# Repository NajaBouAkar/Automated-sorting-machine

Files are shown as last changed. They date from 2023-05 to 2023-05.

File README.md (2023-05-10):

# Automated-sorting-machine

# Installation
Use the package manager pip to install
```bash
pip install python-socketio
```
```bash
pip install scikit-fuzzy
```
```bash
pip install math smbus time
```
```bash 
pip install numpy
```
```bash
apt-get install rpi.gpio
```
You also have to download a git repo to be able to use the MPUs
```bash
git clone https://github.com/rocheparadox/Kalman-Filter-Python-for-mpu6050.git
```
Now for the installation on the laptop
```bash
pip install scikit-fuzzy
```
```bash
pip install numpy
```
```bash
pip install opencv-python
```

# Implementation
To run the code you fisrt have to get the IP address from the pi and replace it in the code running on the laptop. After that you run the code on the pi then you run the code on the laptop and the sorting will start.
Note: you need to place the dnn model in the same directory as your code.

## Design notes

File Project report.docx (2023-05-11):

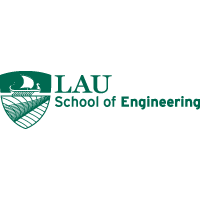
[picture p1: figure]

# LEBANESE AMERCIAN UNIVERSITY

# MCE411– Mechatronic System Design 2

# Doctor Noel Maalouf

# Project report

# Rami Hjeij: #ID 202001988

# Hassan Al Hakim #ID 202000443

# Naja Bou Akar #ID 202000174

Date of Submission: 5/10/2023

# Figures:

# Methodology:

## Design:

To layout the three degree of freedom robot arm with a gripper that is capable of picking up and sorting cups and bottles which are located on a conveyor belt, we accompanied a based technique that concerned numerous key steps. First, we performed a thorough evaluation of the problem and the favored outcome, along with an in depth examine of the conveyor belt, the objects to be picked up, and the overall surroundings. We then evolved a clean and concise specification for the robotic arm, such as its size, weight, and variety of movement, as well as the desired accuracy and precision for object detection and sorting.

Next, we used an existing layout for the robot arm that we got from grabCAD, which include motors, sensors, contemplating factors such as price, reliability, and simplicity of integration.

Once the design was finalized, we proceeded to construct and take a look at the robot arm, iteratively refining and enhancing its capability primarily based on the consequences of our assessments. Finally, we included the arm with the object detection machine and conveyor belt manipulate mechanism, ensuring seamless communique and coordination among all additives. This technique allowed us to design and construct an excellent robot arm that meets the specific necessities of the application efficiently and correctly.

### Robotic arm:

- 3D printed robotic arm
- 3 MG996R servos
- 1 SG90 9g servo
- 2 MPU 6050
- Screws
- 2 Lithium batteries (3.7V)

As shown in the figure, the robotic arm comprises a rotating base link and two moving links, in addition to a gripper that has the ability to open and close. The two MPUs located on the moving links provide the actual angle of each link, which can serve as input for the fuzzy logic controller responsible for the arm's movements.

To power the servo motors, two lithium batteries are utilized, which supply the rated voltage required. Additionally, the servo motors share common ground with the Raspberry Pi.

However, due to a malfunction in one of the MPUs, the arm was ultimately designed to operate with only three degrees of freedom instead of the originally intended four degrees.

### Conveyor belt:

- 12 V DC motor (high torque)
- Metal coupling
- 5 bearings
- 2 pipes
- Rubber
- Screws and bolts
- H-bridge
- AC to DC transformer (220VAC to 12VDC)
- Grease

As shown in the figure above, the conveyor belt is equipped with five bearings, four of which are inserted inside the green pipes. These pipes have a metallic rod inserted through them, which functions as a center axis. Three of these metallic rods will be fixed to the chassis of the belt, while the fourth one will be fixed to the coupling. The coupling, in turn, will be attached to the motor, such that when the motor rotates, the entire belt will rotate.

To power the motor, a transformer is used to supply rated voltage for the h-bridge which also shares common ground with the Raspberry Pi.

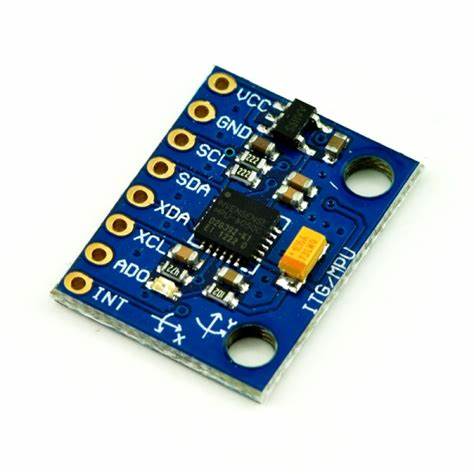
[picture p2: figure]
Triple Axis Accelerometer & Gyro - MPU-6050

Figure 1:MPU6050

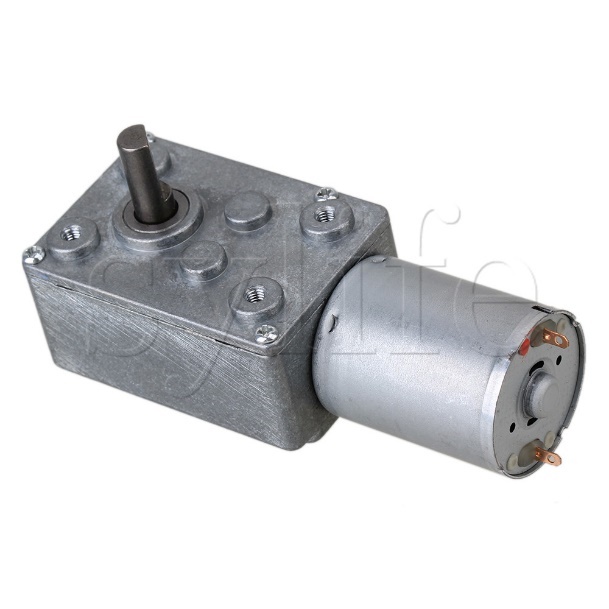
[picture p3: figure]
High Torque 12V DC 120rpm DC Worm Geared Motor With Gear Reducer Turbo ...

Figure 2: High Torque 12V DC Motor

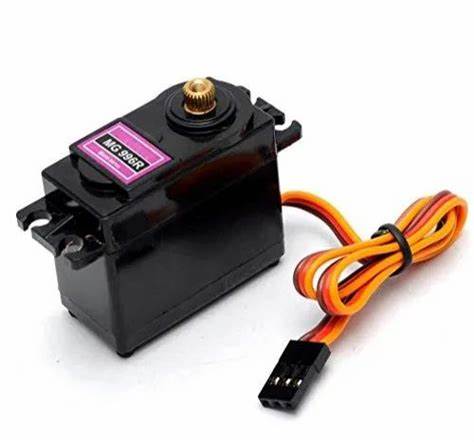
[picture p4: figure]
Mg996 Towerpro Mg996r High Torque Metal Gear Servo Motor 360 Degree ...

Figure 3: MG996R Servo Motor

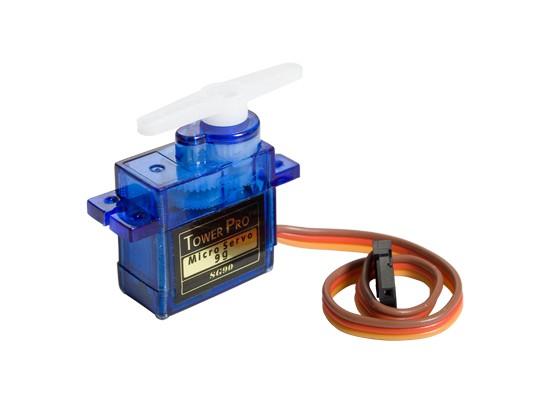
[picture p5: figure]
Makerobot Education: Servo Motor Interfacing With Arduino Uno

Figure 4: SG90 9g Servo Motor

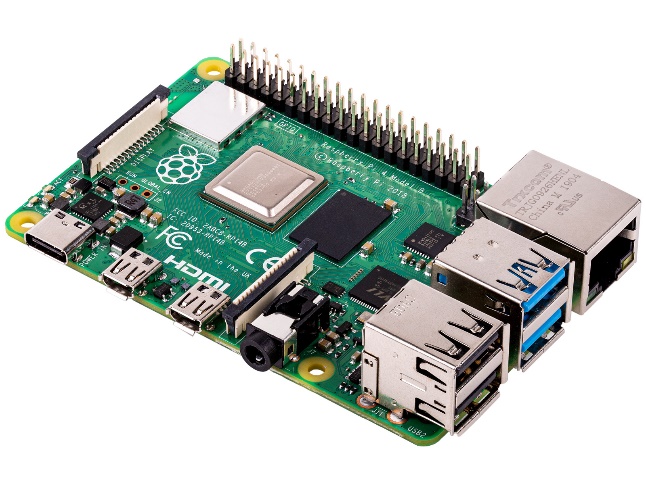
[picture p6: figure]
Raspberry Pi 4 released - everything changes, but the price remains the ...

Figure 5: Raspberry Pi 4

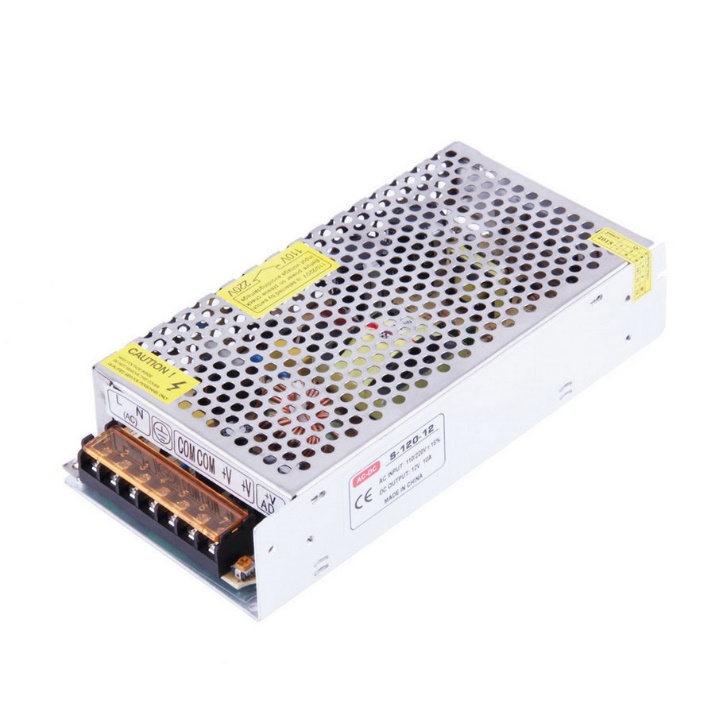
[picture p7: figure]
AC 120V 220V To DC 12V Regulated Transformer Power Supply For LED Strip ...

Figure 6: AC to DC transformer (220VAC to 12VDC)

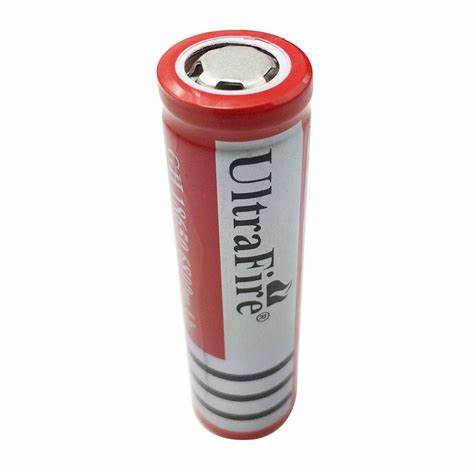
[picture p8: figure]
1/2/4/6/10pcs Flat Top 18650 Batterie 6800mAh 3.7V Li-ion Rechargeable ...

Figure 7: 3.7V 6800mah lithium battery

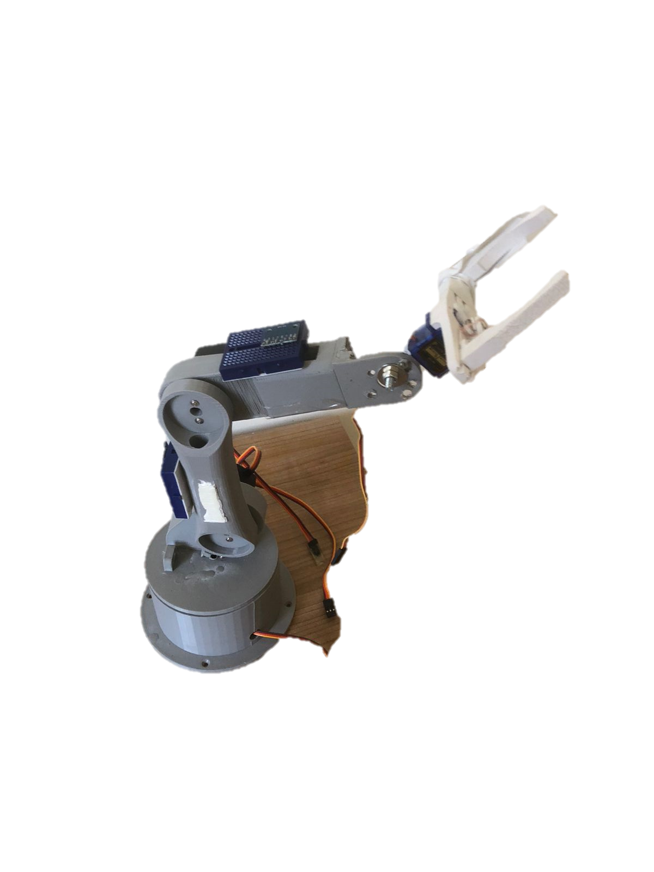
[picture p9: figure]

Figure 8: 3D printed Robotic Arm

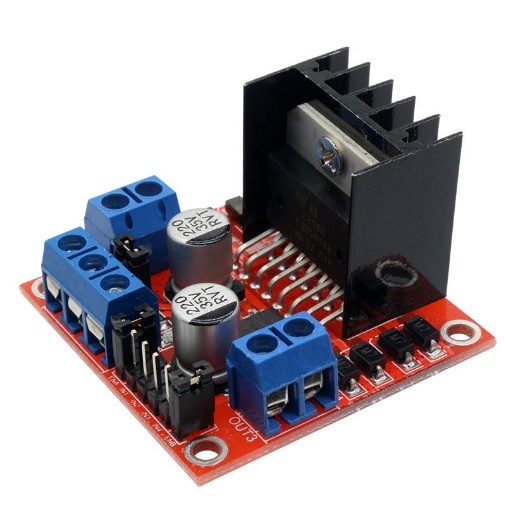
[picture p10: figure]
L298N H-Bridge Stepper Motor Driver Module for Arduino | Satistronix Group

Figure 9: L298 H-Bridge

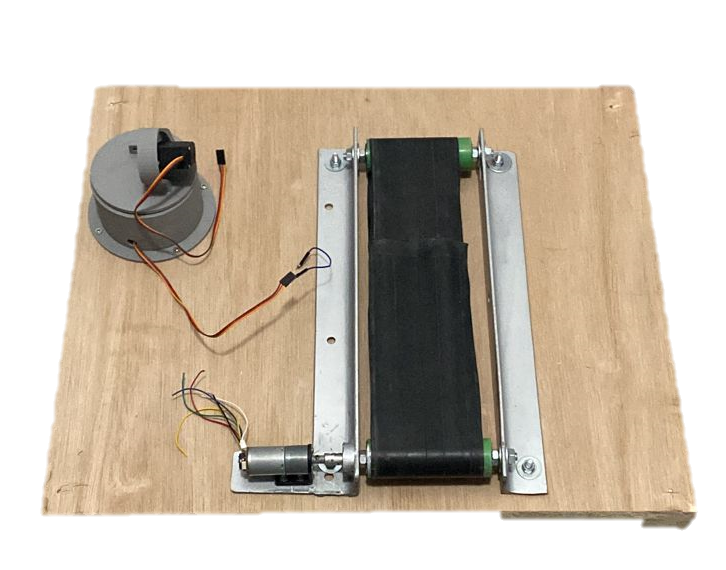
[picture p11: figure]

Figure 10: Conveyer Belt with its base

## Simulation:

We utilized two Fuzzy Logic controllers to control our system. The first controller was used for the belt, and it relied on the centered pixel of the object as feedback. The second controller was used for the robotic arm, and it relied on feedback from the MPU6050 sensor from two different links.

### Belt:

To obtain the universe of discourse, we measured the position of the pixel along the x-axis at different locations on the belt, as well as the desired pixel position. The output of the fuzzy logic is a Pulse Width Modulation (PWM) signal, which is then sent to the motor. Furthermore, we tested the angular velocity for different PWM outputs to determine the desired universe of discourse for the output. All of the codes were implemented using Python and the SKFuzzy library.

Figure 11: Universe of discourse of the bottle

Figure 12: Universe of discourse of the Cup.

To take enough data about the x-coordinates that will be faced in our application, we turned on the motor with the bottle on the belt so that the model can detect the bottle on different positions until reaching the desired position. Then we printed the x-coordinates for all the positions that were detected by the model as shown above. The same was done to know the universe of discourse for the cup. From the data shown in the figure above we chose that the universe of discourse must be between 900 and 580 (which is the desired position). Also, from the increments we got we chose the membership functions for the input as shown in fig.13:

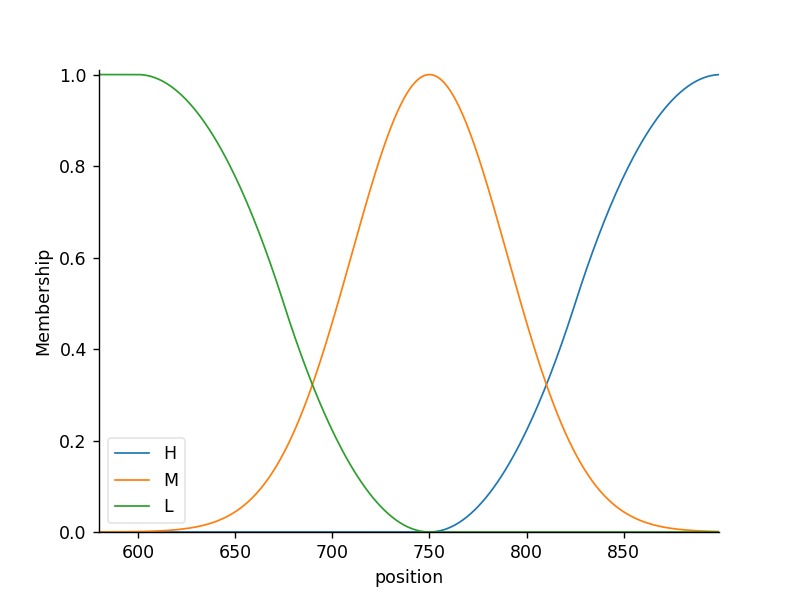
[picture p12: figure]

Figure 13: Input membership function of the belt

Figure 14: Python code for input membership functions

The universe of discourse is [580,900].

Our desired pixel is 580.

Low is from 580 to 750.

Medium is 600 to 900.

High is from 750 to 900.

All parameters have been chosen experimentally.

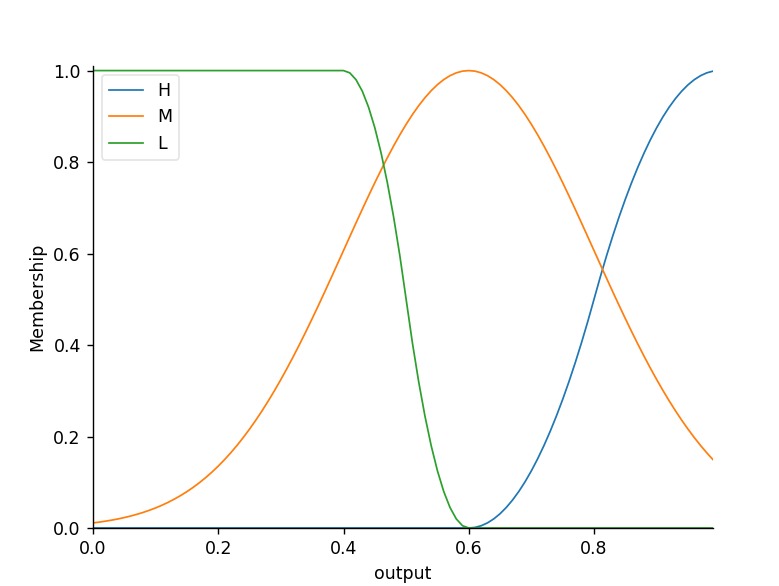
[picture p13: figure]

Figure 15: Python code for the output

Universe of discourse is [0 1].

Low is from 0 to 0.6.

Medium is 0 to 1.

High is from 0.6 to 1.

Also, parameters have been chosen experimentally. The experiments were testing the speed of the belt when subjected to multiple PWM signals.

Figure 16:Python code for the rules of the belt controller

The rules were as follow:

If the position is high then the output is high.

If the position is medium then the output is medium.

If the position is low then the output is low.

Figure 17: Output to a given input

For an input of 650 which means that our center of our object x-axis coordinate is equal to 650 the output to be given to the motor is 0.28.

### Robotic arm:

The assumed input universe of discourse ranges from -90 to 90 degrees, since the servo motor rotates from 0 to 180 degrees. As a result, if the error were to be greater than 90 or less than -90 degrees, it would indicate a malfunction in the servo motor. The output universe of discourse is set between -10 to 10 to ensure that the process runs smoothly, without any sudden or aggressive changes.

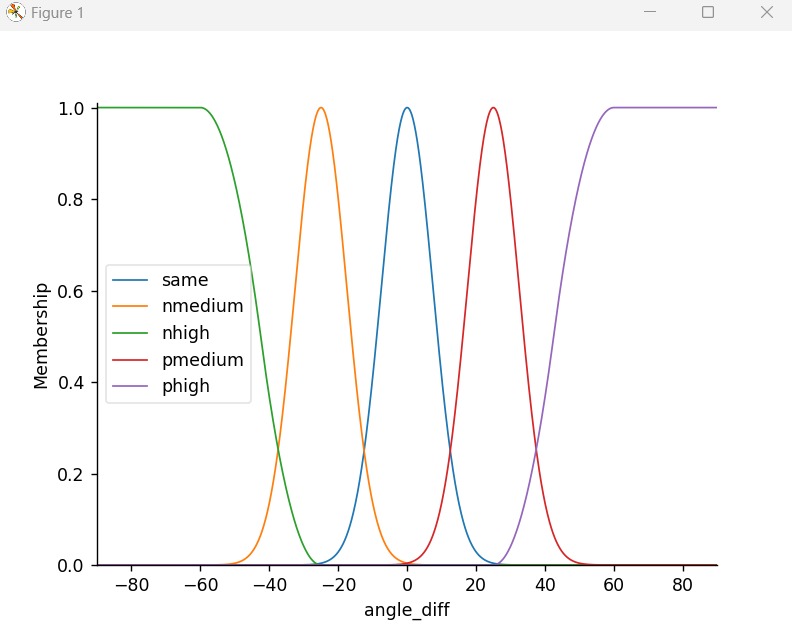
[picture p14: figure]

Figure 18: Input membership function

Figure 19: Python code to create input membership function

The input provided is the difference between the desired angle and the current angle of the links. The angle difference can fall within different ranges. It can be the same, ranging from -25 to 25. It can also be negative and medium, ranging from -50 to 0. Alternatively, it can be negative and high, ranging from -90 to -25. Additionally, it can be positive and medium, ranging from 0 to 50, and finally, positive, and high, ranging from 25 to 90.

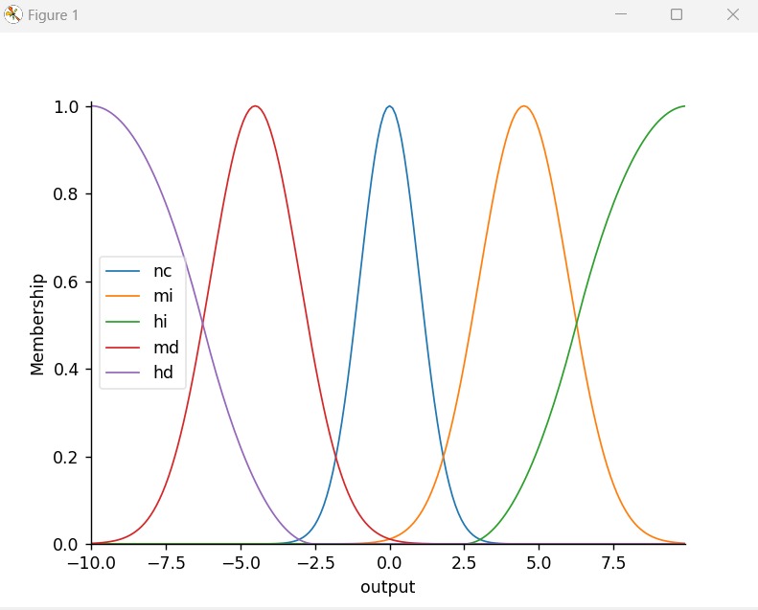
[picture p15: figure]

Figure 20: Output Membership functions

The resulting output is the angle that needs to be added to the current servo motor angle. This angle can also indicate no change, ranging between -3 to 3 degrees. It can also indicate a medium increase, ranging from 0 to 8 degrees, and a high increase, ranging from 2.5 to 10 degrees. Additionally, it can indicate a medium decrease, ranging from -10 to 0 degrees, and finally, a high decrease, ranging from -10 to -2.5 degrees.

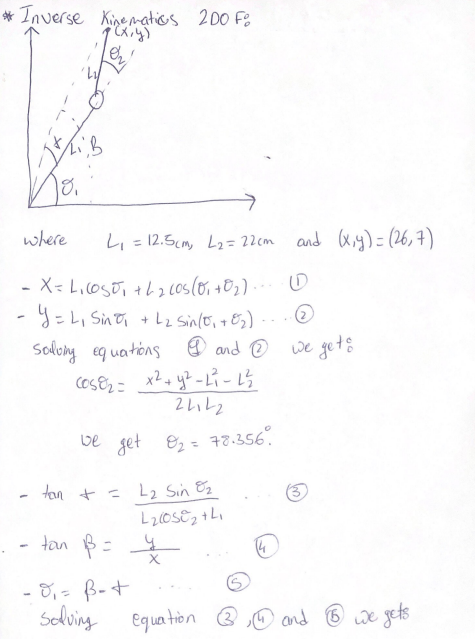
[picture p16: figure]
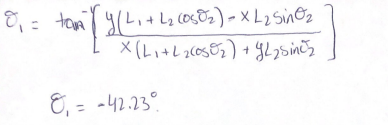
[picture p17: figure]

Figure 21: Inverse Kinematic

To determine the desired angle output for each link, we used inverse kinematics after measuring the x and y coordinates of our object with respect to the center of our robotic arm:

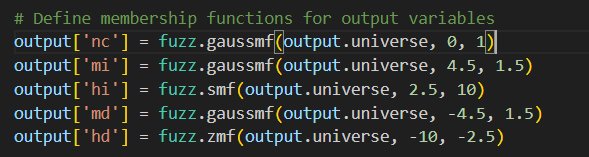
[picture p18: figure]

Figure 22: Python code to create output membership functions

Figure 23: Sample input testing

An example output was obtained when the input value was set to 10, resulting in an output of 1.755.

## Implementation:

### Process of sorting:

Our object detection code relied on a pretrained YOLOv4 model running on a laptop with an external webcam. To communicate with the Raspberry Pi, we established a socket connection, where the laptop acted as the server, transmitting information to the client (Raspberry Pi). The client was designed to wait for a connection before executing the code. Mainly the code on the laptop will take the video from the webcam, use the computer vision model to detect at each frame if there is bottle or cup. Moreover, the x-coordinate position of the object will be fed to the fuzzy logic controller, and the controller will provide the needed PWM signal for the motor. Then this output will be transmitted as a string to the raspberry pi code through a socket, the code on the pi will decode it and feed it to the motor.

Once the object detection and fuzzy logic control of the belt processing were complete, the laptop would send a required PWM signal to the motor. The fuzzy logic controller would then execute again on the laptop to obtain another PWM signal, appropriate for the new position of the object. This process would repeat until convergence was reached, at which point the roles would reverse, with the Raspberry Pi becoming the server and the laptop becoming the client.

After the belt fuzzy controller converged, we used a fuzzy logic controller to set the robotic arm in the desired position, grab the object, and transport it to its corresponding location on the left or right of the arm. Once the object was sorted, the Raspberry Pi would send a signal to the laptop via sockets indicating that the process was complete, triggering the object detection code and fuzzy logic controller of the belt on the laptop to repeat the process.

## Problems in the testing phase:

1- Model Training: First, we decided to train our own model that supports and differentiates between two different well-defined objects. So, we started with a dataset of 300 images and we used roboflow to annotate our images and got our XML files. Now for the training we trained using the mobilenet SSD V2 (which has very fast inferencing time and high accuracy). After the training had finished, we converted our model to a tflite model and deployed it on the raspberry pi. When it was deployed the model was acting weird and was detecting everything and labeling them as a bottle. Second, we thought that we needed a bigger dataset so we took 500 more pictures to have a total of 800 images to train our model. In addition to the new pictures, we augmented the data to finally have a total of 2100 images to train our model. However, we still had the same error. That is why we decided to use a pretrained YOLOV4 model that we downloaded online. This model can differentiate between 73 classes but we only used two classes (bottle and cup).
2- MPU calibration: When the MPUs were tested they were giving inaccurate data so we needed to apply the Kalman Filter algorithm which stabilized the outputs of the MPUs. The code for the Kalman filter algorithm was downloaded from a GitHub repository named Kalman.
3- 3 DOF: The initial design of the robot was a four degree of freedom mechanism, however one of the three MPUs was defective, so we fixed one of the Links.
4- Resistors: In order to have one power supply for the machine, we tried to use 4.7-ohm resistors to divide the voltage from 12V to 5V to feed the servo motors. However, the resistors did not withstand the current absorbed by the servos. To solve this problem, we were obligated to use two 3.7V lithium batteries to supply the servo motors alone.
5- Servo Motors: The MG996R servo motors have a problem in holding their position which creates some oscillations in their behavior. Also, when testing the gripper its servo motor malfunctioned suddenly, so we used another gripper that was available that uses the SG90 servo motor.

# Results and Limitations:

## Limitations:

1- The robotic arm can be implemented with more stable servo motors which can increase the accuracy of the machine.
2- Our model operates properly in certain lighting conditions, a better model can be implemented which will make the machine more reliable.
3- Our machine is trained to sort only two objects, which are the bottle and the cup.
4- Camera calibration techniques can be used so that the model can operate properly regardless of its position.

## Results:

We are pleased to present the results of our project which exceeded all expectations and proved to be a great success. Our team’s unwavering commitment that helped us overcome all the challenges that we encountered through our journey in this project, meticulous planning and relentless pursuit of excellence have allowed us to achieve incredible results. By employing innovative techniques and using cutting-edge technology we were able to make the automated sorting machine that was able to continuously sort a bottle and a cup using computer vision. All fuzzy controllers were working with high efficiency and accuracy and the connection between the laptop and the raspberry pi was very effective and working very smoothly.

Project git hub repository:

https://github.com/RamiHjeij/Autonomous-Sorting-Machine.git

Video: https://drive.google.com/file/d/1pVdlkhVqWchsBrMoY4FO01Fo6XS_HtjN/view?usp=sharing

# References:

https://github.com/rocheparadox/Kalman-Filter-Python-for-mpu6050.git

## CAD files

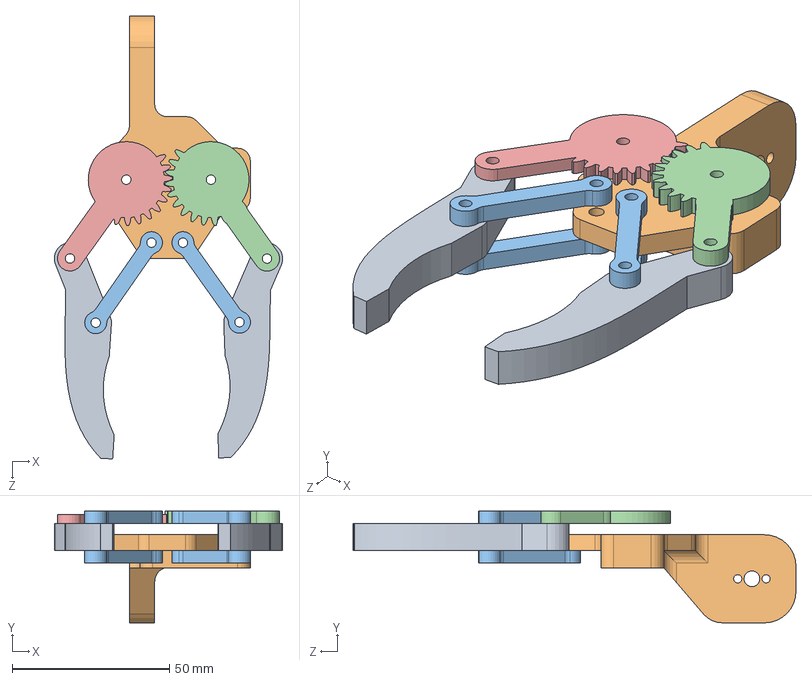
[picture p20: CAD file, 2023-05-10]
SW file/Gripper/Gripper Assembly_r1.SLDASM
72.5 x 35.5 x 140.7 mm
gear1_r1
gear2_r1
grip link 1_r1 x 4
Gripper base_r1
Gripper 1_r1 x 2

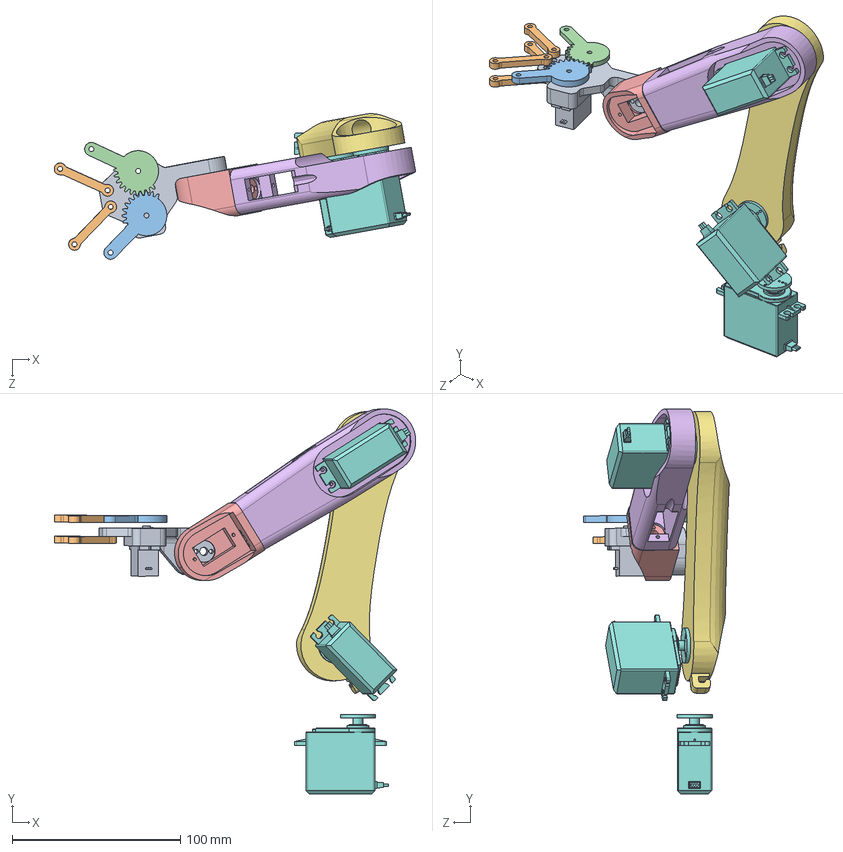
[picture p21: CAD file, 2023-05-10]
SW file/Robotic Arm.SLDASM
214.9 x 228.9 x 86.7 mm
Servo Motor MG996R x 3
Arm 01
Arm 02 v3
Arm 03
gear1
gear2
grip link 1 x 4
Gripper base
Servo Motor Micro 9g

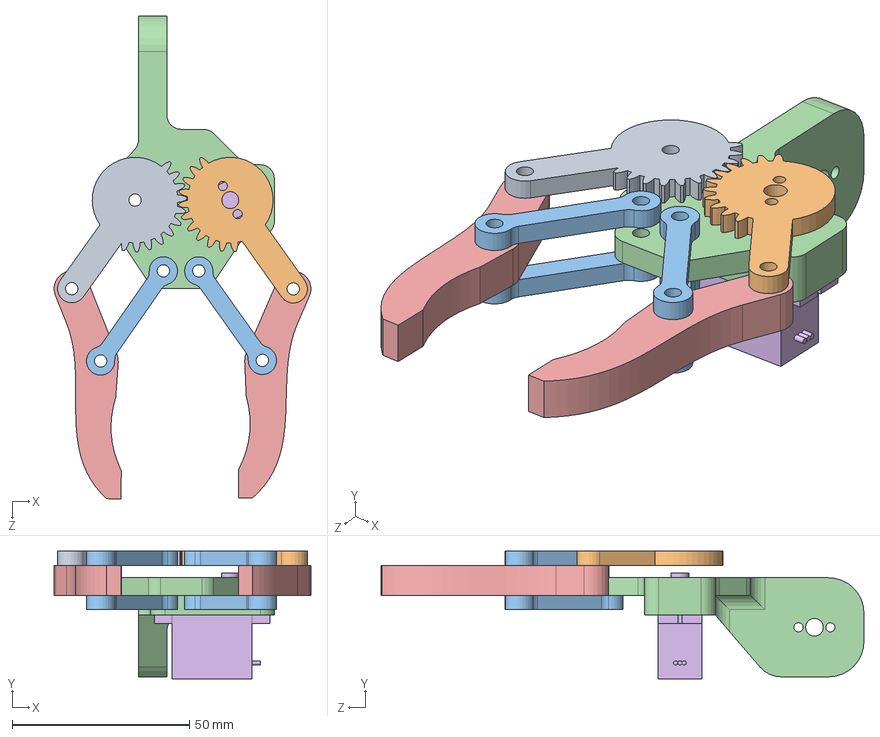
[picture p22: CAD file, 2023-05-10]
SW file/Gripper/Gripper Assembly.SLDASM
72.5 x 36.0 x 136.4 mm
gear1
gear2
grip link 1 x 4
Gripper base
Gripper 1 x 2
Servo Motor Micro 9g

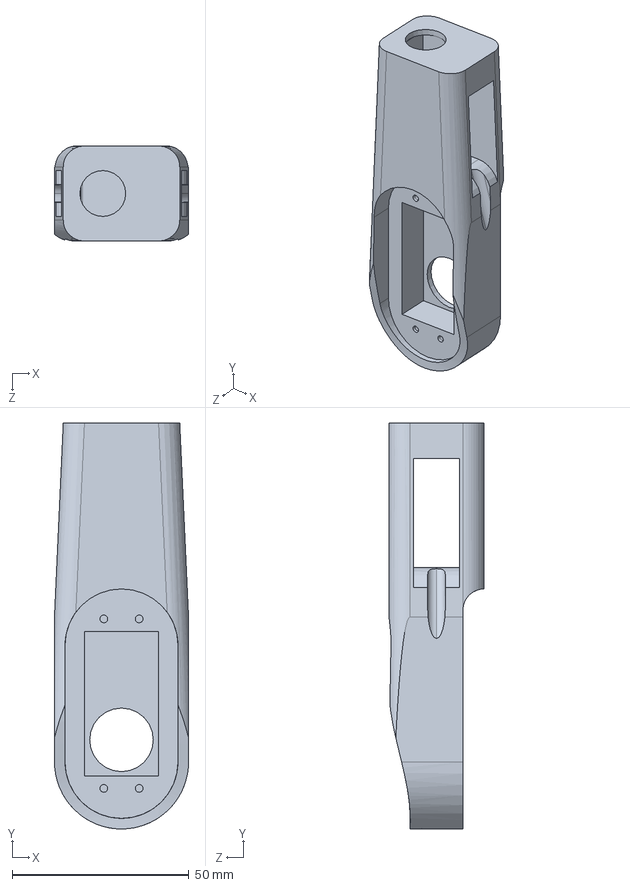
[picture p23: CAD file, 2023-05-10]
SW file/Arm 02 v3_r1.SLDPRT
38.0 x 115.0 x 27.0 mm

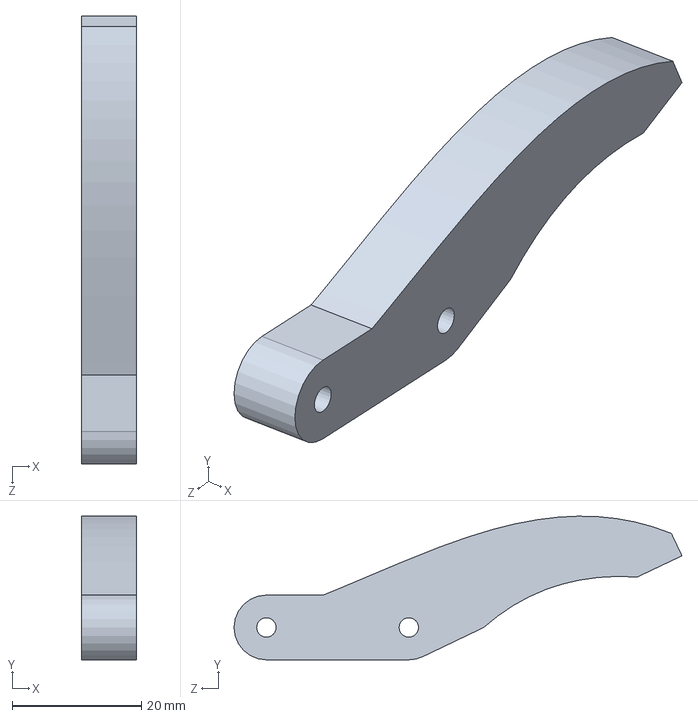
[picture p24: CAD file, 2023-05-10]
SW file/Gripper/Gripper 1_r1.SLDPRT
8.50 x 22.2 x 69.2 mm

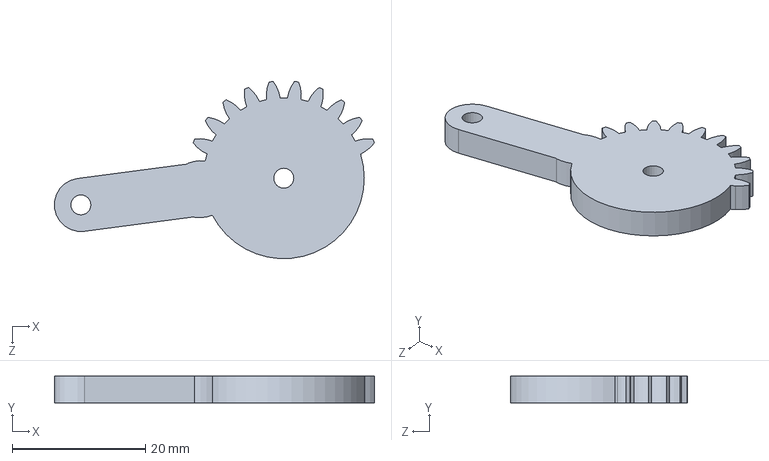
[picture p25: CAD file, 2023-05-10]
SW file/Gripper/gear2_r1.SLDPRT
48.1 x 4.00 x 26.6 mm

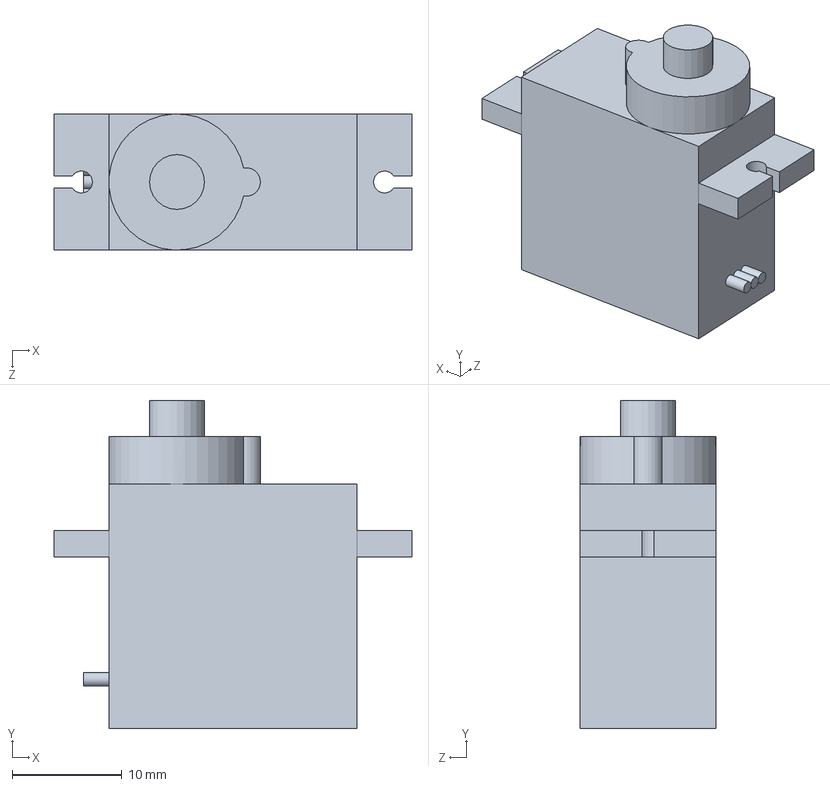
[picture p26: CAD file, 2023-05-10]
SW file/Servo Motor Micro 9g.SLDPRT
32.6 x 29.9 x 12.4 mm

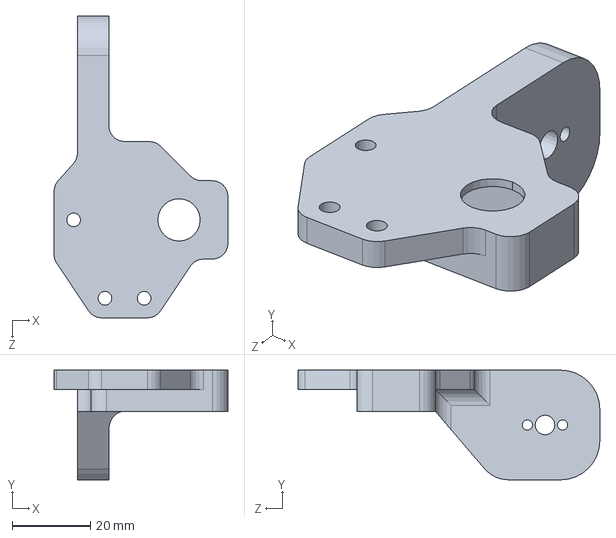
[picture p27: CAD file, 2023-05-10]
SW file/Gripper/Gripper base_r1.SLDPRT
44.4 x 28.0 x 77.0 mm

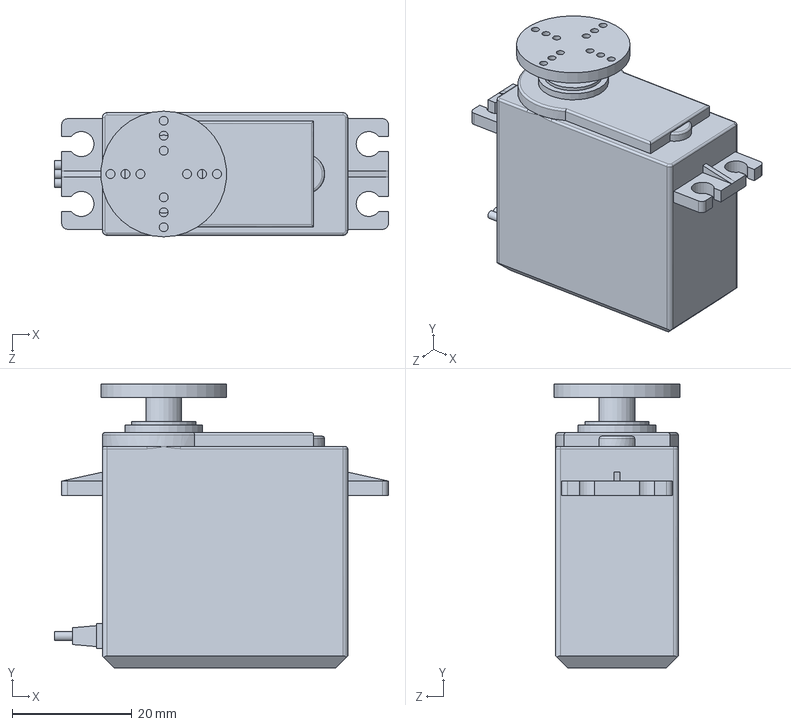
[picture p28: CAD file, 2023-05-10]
SW file/Servo Motor MG996R.SLDPRT
55.8 x 47.4 x 21.0 mm

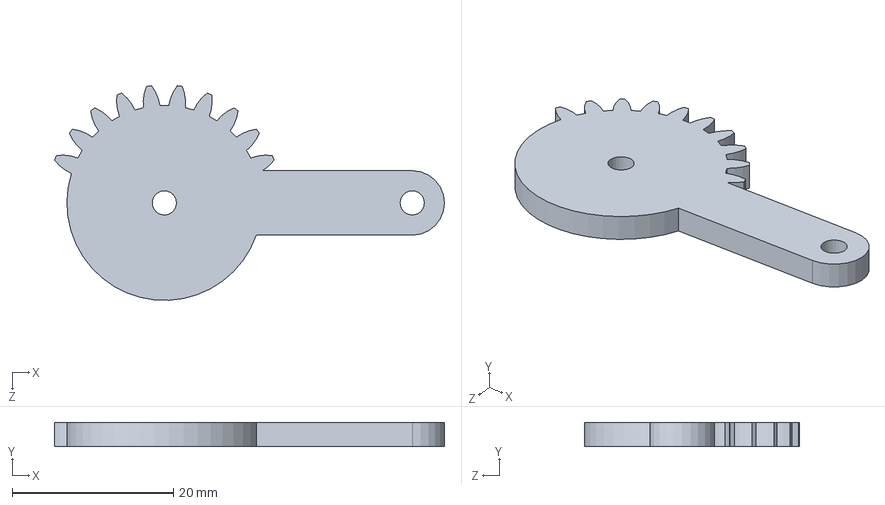
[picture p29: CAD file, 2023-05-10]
SW file/Gripper/gear1.SLDPRT
48.4 x 3.00 x 26.6 mm

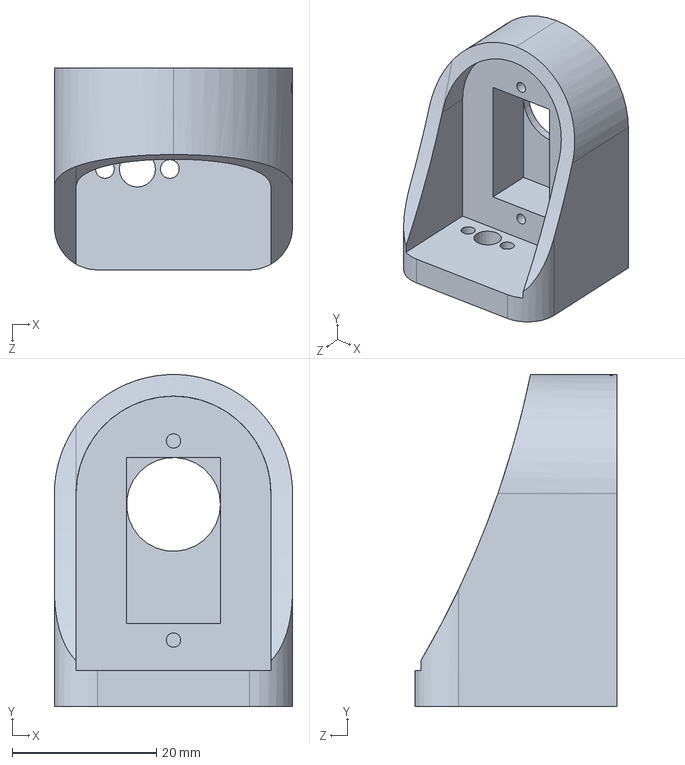
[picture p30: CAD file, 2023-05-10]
SW file/Arm 03_r1.SLDPRT
33.0 x 46.0 x 28.0 mm

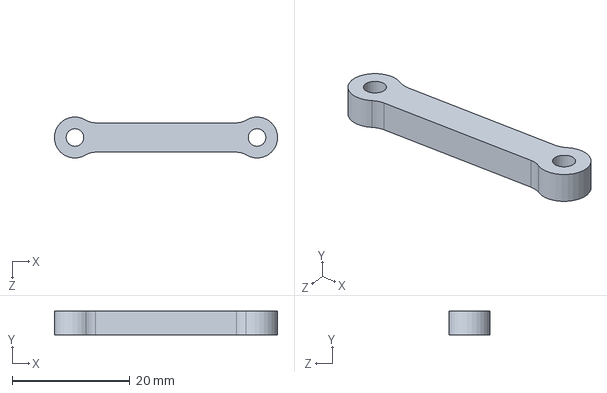
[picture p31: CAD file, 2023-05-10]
SW file/Gripper/grip link 1.SLDPRT
38.0 x 4.00 x 6.96 mm

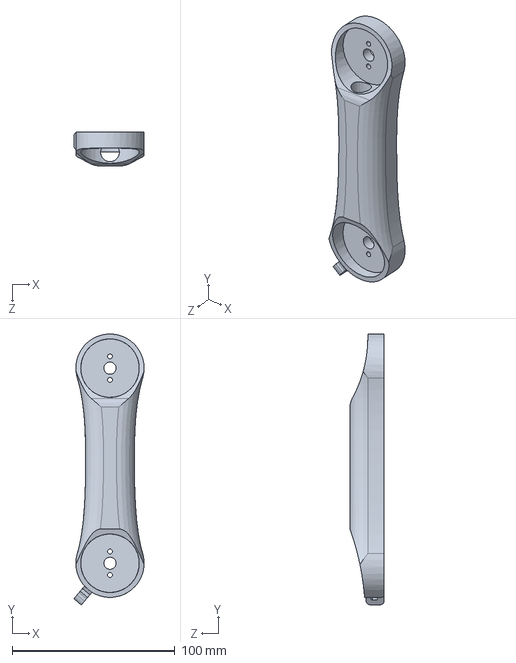
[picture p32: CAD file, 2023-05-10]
SW file/Arm 01.SLDPRT
43.2 x 166.7 x 21.0 mm

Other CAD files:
SW file/Arm 02 v3.SLDPRT
SW file/Gripper/Gripper base.SLDPRT
SW file/Gripper/gear1_r1.SLDPRT
SW file/Arm 03.SLDPRT
SW file/Gripper/gear2.SLDPRT
SW file/Arm 01_r1.SLDPRT
SW file/Arm 02 v2.SLDPRT
SW file/Arm 02.SLDPRT
SW file/Base.SLDPRT
SW file/Base_r1.SLDPRT
SW file/Gripper/Gripper 1 v2.SLDPRT
SW file/Gripper/Gripper 1.SLDPRT
SW file/Gripper/grip link 1_r1.SLDPRT
SW file/Servo Motor MG996R_r1.SLDPRT
SW file/Servo Motor Micro 9g_r1.SLDPRT
SW file/Test 01.SLDPRT
SW file/Waist.SLDPRT
SW file/Waist_r1.SLDPRT

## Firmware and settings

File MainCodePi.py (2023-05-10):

#Connections
#MPU6050 - Raspberry pi
#VCC - 5V  (2 or 4 Board)
#GND - GND (6 - Board)
#SCL - SCL (5 - Board)
#SDA - SDA (3 - Board)
#Servo Motor 1:
#PWM - GPIO (18 - Board)
#Servo Motor 2:
#PWM - GPIO (16 - Board)
#Servo Motor 3:
#PWM - GPIO (13 - Board)
#Servo Motor 4:
#PWM - GPIO (12 - Board)
#H-Bridge:
#PWM - GPIO (15 - Board)
#In1 - GPIO (29 - Board)
#In2 - GPIO (31 - Board)

#This code depends on the library KalmanAngle that have the following URL:https://github.com/rocheparadox/Kalman-Filter-Python-for-mpu6050.git



from Kalman import KalmanAngle
import smbus                  #import SMBus module of I2C
import time
import math
import RPi.GPIO as GPIO
import numpy as np
import skfuzzy as fuzz
from skfuzzy import control as ctrl
import RPi.GPIO as GPIO
from time import sleep
import socket

# Set up the pins
PWM_PIN = 15
IN1_PIN = 29
IN2_PIN = 31

GPIO.setmode(GPIO.BOARD)
GPIO.setup(PWM_PIN, GPIO.OUT)
GPIO.setup(IN1_PIN, GPIO.OUT)
GPIO.setup(IN2_PIN, GPIO.OUT)

pwm = GPIO.PWM(PWM_PIN, 100)
pwm.start(0)
GPIO.setmode(GPIO.BOARD)
# GPIO for servo
GPIO.setup(13, GPIO.OUT)
GPIO.setup(16, GPIO.OUT)
GPIO.setup(12, GPIO.OUT)
GPIO.setup(18, GPIO.OUT)

servo_pwm1 = GPIO.PWM(18, 50)
servo_pwm1.start(0)
servo_pwm2 = GPIO.PWM(16, 50) # 50Hz frequency
servo_pwm2.start(0) # start PWM with 0% duty cycle
servo_pwm3 = GPIO.PWM(13, 50) # 50Hz frequency
servo_pwm3.start(0) # start PWM with 0% duty cycle
servo_pwm4 = GPIO.PWM(12, 50)
servo_pwm4.start(0)

kalmanX = KalmanAngle()
kalmanY = KalmanAngle()
kalmanX2 = KalmanAngle()
kalmanY2 = KalmanAngle()
bus = smbus.SMBus(1)
RestrictPitch = True    #Comment out to restrict roll to ±90deg instead
radToDeg = 57.2957786
kalAngleX = 0
kalAngleY = 0
kalAngleX2 = 0
kalAngleY2 = 0
#some MPU6050 Registers and their Address
PWR_MGMT_1   = 0x6B
SMPLRT_DIV   = 0x19
CONFIG       = 0x1A
GYRO_CONFIG  = 0x1B
INT_ENABLE   = 0x38
ACCEL_XOUT_H = 0x3B
ACCEL_YOUT_H = 0x3D
ACCEL_ZOUT_H = 0x3F
GYRO_XOUT_H  = 0x43
GYRO_YOUT_H  = 0x45
GYRO_ZOUT_H  = 0x47

def set_angle1(angle):
    duty_cycle = (angle / 18.0) + 2.5 # convert angle to duty cycle
    servo_pwm1.ChangeDutyCycle(duty_cycle)
    time.sleep(.05) # wait for servo to reach the desired angle
def set_angle2(angle):
    duty_cycle = (angle / 18.0) + 2.5 # convert angle to duty cycle
    servo_pwm2.ChangeDutyCycle(duty_cycle)
    time.sleep(.05) # wait for servo to reach the desired angle

def set_angle3(angle):
    duty_cycle = (angle / 18.0) + 2.5 # convert angle to duty cycle
    servo_pwm3.ChangeDutyCycle(duty_cycle)
    time.sleep(.05) # wait for servo to reach the desired angle

def set_angle4(angle):
    duty_cycle = (angle / 18.0) + 2.5 # convert angle to duty cycle
    servo_pwm4.ChangeDutyCycle(duty_cycle)
    time.sleep(.05) # wait for servo to reach the desired angle

#Read the gyro and acceleromater values from MPU6050


def MPU_Init(Address):
      #write to sample rate register
      bus.write_byte_data(Address, SMPLRT_DIV, 7)

      #Write to power management register
      bus.write_byte_data(Address, PWR_MGMT_1, 1)

      #Write to Configuration register
      #Setting DLPF (last three bit of 0X1A to 6 i.e '110' It removes the noise due to vibration.) https://ulrichbuschbaum.wordpress.com/2015/01/18/using-the-mpu6050s-dlpf/
      bus.write_byte_data(Address, CONFIG, int('0000110',2))

      #Write to Gyro configuration register
      bus.write_byte_data(Address, GYRO_CONFIG, 24)

      #Write to interrupt enable register
      bus.write_byte_data(Address, INT_ENABLE, 1)


def read_raw_data(Address,addr):
      #Accelero and Gyro value are 16-bit
      high = bus.read_byte_data(Address, addr)
      low = bus.read_byte_data(Address, addr+1)

      #concatenate higher and lower value
      value = ((high << 8) | low)

      #to get signed value from mpu6050
      if(value > 32768):
            value = value - 65536
      return value

# Set the motor direction
def set_direction(direction):
    if direction == 'f':
        GPIO.output(IN1_PIN, GPIO.HIGH)
        GPIO.output(IN2_PIN, GPIO.LOW)
    elif direction == 'b':
        GPIO.output(IN1_PIN, GPIO.LOW)
        GPIO.output(IN2_PIN, GPIO.HIGH)
    else:
        # Stop the motor if the direction is not recognized
        GPIO.output(IN1_PIN, GPIO.LOW)
        GPIO.output(IN2_PIN, GPIO.LOW)

# Run the motor at a given speed
def run_motor(speed):
    pwm.ChangeDutyCycle(speed * 100)
   
server_socket = socket.socket(socket.AF_INET, socket.SOCK_STREAM)

server_socket.bind(('0.0.0.0', 5555))

server_socket.listen()

client_socket, client_address = server_socket.accept()


bus = smbus.SMBus(1) #for older version boards
DeviceAddress = 0x68   # MPU6050 device address

DeviceAddress2 = 0x69

MPU_Init(DeviceAddress)
MPU_Init(DeviceAddress2)
while True:
      set_angle2(180) #rotate servo to 90 degrees
      set_angle3(40)
      set_angle1(90)
      set_angle4(180)
      time.sleep(1)
      while True:
            data = client_socket.recv(1024).decode().strip()
            print(data)
            if data == 'stop_code':
                  
                  break
            elif data=='bottle':
                  Object=True
            elif data=='cup':
                  Object=False
            elif data == 'stop':
                  print(data)

                  set_direction('s')

            else:
                  print(data)
                  
                  speed = float(data)
                  set_direction('b')
                  run_motor(speed)
                  
      angle_diff = ctrl.Antecedent(np.arange(-90, 90, 0.1), 'angle_diff')
      # Define membership functions for input variable

      angle_diff['same'] = fuzz.gaussmf(angle_diff.universe, 0, 7.5)

      angle_diff['nmedium'] = fuzz.gaussmf(angle_diff.universe, -25, 7.5)

      angle_diff['nhigh'] = fuzz.zmf(angle_diff.universe, -60, -25)

      angle_diff['pmedium'] = fuzz.gaussmf(angle_diff.universe, 25, 7.5)

      angle_diff['phigh'] = fuzz.smf(angle_diff.universe, 25, 60)

      

      # Define output variables

      output = ctrl.Consequent(np.arange(-10, 10, 0.1), 'output')

      

      # Define membership functions for output variables

      output['nc'] = fuzz.gaussmf(output.universe, 0, 1)

      output['mi'] = fuzz.gaussmf(output.universe, 4.5, 1.5)

      output['hi'] = fuzz.smf(output.universe, 2.5, 10)

      output['md'] = fuzz.gaussmf(output.universe, -4.5, 1.5)

      output['hd'] = fuzz.zmf(output.universe, -10, -2.5)

      # Define rules

      rule1 = ctrl.Rule(angle_diff['same'], output['nc'])

      rule2 = ctrl.Rule(angle_diff['nmedium'], output['md'])

      rule3 = ctrl.Rule(angle_diff['nhigh'], output['hd'])

      rule4 = ctrl.Rule(angle_diff['pmedium'], output['mi'])

      rule5 = ctrl.Rule(angle_diff['phigh'], output['hi'])

      # Define fuzzy system and add rules
      fuzzy_ctrl = ctrl.ControlSystem([rule1, rule2, rule3, rule4, rule5])

      # Define simulation
      simulation = ctrl.ControlSystemSimulation(fuzzy_ctrl)

     

      time.sleep(1)
      #Read Accelerometer raw value
      accX = read_raw_data(DeviceAddress,ACCEL_XOUT_H)
      accY = read_raw_data(DeviceAddress,ACCEL_YOUT_H)
      accZ = read_raw_data(DeviceAddress,ACCEL_ZOUT_H)
      accX2 = read_raw_data(DeviceAddress2,ACCEL_XOUT_H)
      accY2 = read_raw_data(DeviceAddress2,ACCEL_YOUT_H)
      accZ2 = read_raw_data(DeviceAddress2,ACCEL_ZOUT_H)

      if (RestrictPitch):
            roll = math.atan2(accY,accZ) * radToDeg
            pitch = math.atan(-accX/math.sqrt((accY**2)+(accZ**2))) * radToDeg
            roll2 = math.atan2(accY2,accZ2) * radToDeg
            pitch2 = math.atan(-accX2/math.sqrt((accY2**2)+(accZ2**2))) * radToDeg
      else:
            roll = math.atan(accY/math.sqrt((accX**2)+(accZ**2))) * radToDeg
            pitch = math.atan2(-accX,accZ) * radToDeg
            roll2 = math.atan(accY2/math.sqrt((accX2**2)+(accZ2**2))) * radToDeg
            pitch2 = math.atan2(-accX2,accZ2) * radToDeg

      kalmanX.setAngle(roll)
      kalmanY.setAngle(pitch)
      kalmanX2.setAngle(roll2)
      kalmanY2.setAngle(pitch2)
      gyroXAngle = roll;
      gyroYAngle = pitch;
      gyroXAngle2 = roll2;
      gyroYAngle2 = pitch2;
      compAngleX = roll;
      compAngleY = pitch;
      compAngleX2 = roll2;
      compAngleY2 = pitch2;
      timer = time.time()
      flag = 0
      T2=180
      T3=40
      start=time.time()
      Tref2=126
      Tref3=144
      diff_angle2=100
      diff_angle3=100

      while abs(diff_angle2)>=5 or abs(diff_angle3)>=10:
            set_angle2(T2)
            set_angle3(T3)
            
            if(flag >100): #Problem with the connection
                  print("There is a problem with the connection")
                  flag=0
                  continue
            try:
                  #Read Accelerometer raw value
                  accX = read_raw_data(DeviceAddress,ACCEL_XOUT_H)
                  accY = read_raw_data(DeviceAddress,ACCEL_YOUT_H)
                  accZ = read_raw_data(DeviceAddress,ACCEL_ZOUT_H)
                  accX2 = read_raw_data(DeviceAddress2,ACCEL_XOUT_H)
                  accY2 = read_raw_data(DeviceAddress2,ACCEL_YOUT_H)
                  accZ2 = read_raw_data(DeviceAddress2,ACCEL_ZOUT_H)
                  #Read Gyroscope raw value
                  gyroX = read_raw_data(DeviceAddress,GYRO_XOUT_H)
                  gyroY = read_raw_data(DeviceAddress,GYRO_YOUT_H)
                  gyroZ = read_raw_data(DeviceAddress,GYRO_ZOUT_H)
                  gyroX2 = read_raw_data(DeviceAddress2,GYRO_XOUT_H)
                  gyroY2 = read_raw_data(DeviceAddress2,GYRO_YOUT_H)
                  gyroZ2 = read_raw_data(DeviceAddress2,GYRO_ZOUT_H)
                  dt = time.time() - timer
                  timer = time.time()


                  if (RestrictPitch):
                        roll = math.atan2(accY,accZ) * radToDeg
                        pitch = math.atan(-accX/math.sqrt((accY**2)+(accZ**2))) * radToDeg
                        roll2 = math.atan2(accY2,accZ2) * radToDeg
                        pitch2 = math.atan(-accX2/math.sqrt((accY2**2)+(accZ2**2))) * radToDeg            
                  else:
                        roll = math.atan(accY/math.sqrt((accX**2)+(accZ**2))) * radToDeg
                        pitch = math.atan2(-accX,accZ) * radToDeg
                        roll2 = math.atan(accY2/math.sqrt((accX2**2)+(accZ2**2))) * radToDeg
                        pitch2 = math.atan2(-accX2,accZ2) * radToDeg
                  gyroXRate = gyroX/131
                  gyroYRate = gyroY/131
                  gyroXRate2 = gyroX2/131
                  gyroYRate2 = gyroY2/131        

                  if (RestrictPitch):
                        set_angle2(T2)
                        set_angle3(T3)
                        if((roll < -90 and kalAngleX >90) or (roll > 90 and kalAngleX < -90)):
                              kalmanX.setAngle(roll)
                              complAngleX = roll
                              kalAngleX   = roll
                              gyroXAngle  = roll
                        else:
                              kalAngleX = kalmanX.getAngle(roll,gyroXRate,dt)

                        if(abs(kalAngleX)>90):
                              gyroYRate  = -gyroYRate
                              kalAngleY  = kalmanY.getAngle(pitch,gyroYRate,dt)
                        if((roll2 < -90 and kalAngleX2 >90) or (roll2 > 90 and kalAngleX2 < -90)):
                              kalmanX2.setAngle(roll2)
                              complAngleX2 = roll2
                              kalAngleX2   = roll2
                              gyroXAngle2  = roll2
                        else:
                              kalAngleX2 = kalmanX2.getAngle(roll2,gyroXRate2,dt)

                        if(abs(kalAngleX2)>90):
                              gyroYRate2  = -gyroYRate2
                              kalAngleY2  = kalmanY2.getAngle(pitch2,gyroYRate2,dt)                
                  else:

                        if((pitch < -90 and kalAngleY >90) or (pitch > 90 and kalAngleY < -90)):
                              kalmanY.setAngle(pitch)
                              complAngleY = pitch
                              kalAngleY   = pitch
                              gyroYAngle  = pitch
                        else:
                              kalAngleY = kalmanY.getAngle(pitch,gyroYRate,dt)

                        if(abs(kalAngleY)>90):
                              gyroXRate  = -gyroXRate
                              kalAngleX = kalmanX.getAngle(roll,gyroXRate,dt)

                        if((pitch2 < -90 and kalAngleY2 >90) or (pitch2 > 90 and kalAngleY2 < -90)):
                              kalmanY2.setAngle(pitch2)
                              complAngleY2 = pitch2
                              kalAngleY2   = pitch2
                              gyroYAngle2  = pitch2
                        else:
                              kalAngleY2 = kalmanY2.getAngle(pitch2,gyroYRate2,dt)

                        if(abs(kalAngleY2)>90):
                              gyroXRate2  = -gyroXRate2
                              kalAngleX2 = kalmanX2.getAngle(roll2,gyroXRate2,dt)                

                      #angle = (rate of change of angle) * change in time
                  gyroXAngle = gyroXRate * dt
                  gyroYAngle = gyroYAngle * dt
                  gyroXAngle2 = gyroXRate2 * dt
                  gyroYAngle2 = gyroYAngle2 * dt
                  
                      #compAngle = constant * (old_compAngle + angle_obtained_from_gyro) + constant * angle_obtained from accelerometer
                  compAngleX = 0.93 * (compAngleX + gyroXRate * dt) + 0.07 * roll
                  compAngleY = 0.93 * (compAngleY + gyroYRate * dt) + 0.07 * pitch
                  compAngleX2 = 0.93 * (compAngleX2 + gyroXRate2 * dt) + 0.07 * roll2
                  compAngleY2 = 0.93 * (compAngleY2 + gyroYRate2 * dt) + 0.07 * pitch2
                  
                  if ((gyroXAngle < -180) or (gyroXAngle > 180)):
                        gyroXAngle = kalAngleX
                  if ((gyroYAngle < -180) or (gyroYAngle > 180)):
                        gyroYAngle = kalAngleY
                  if ((gyroXAngle2 < -180) or (gyroXAngle2 > 180)):
                        gyroXAngle2 = kalAngleX2
                  if ((gyroYAngle2 < -180) or (gyroYAngle2 > 180)):
                        gyroYAngle2 = kalAngleY2
                  
                  print("Angle X: " + str(kalAngleX)+"   " +"Angle Y: " + str(kalAngleY))
                  print("Angle X2: " + str(kalAngleX2)+"   " +"Angle Y2: " + str(kalAngleY2))
                  
                  
                  diff_angle2=Tref2-kalAngleX
                  diff_angle3=Tref3-kalAngleX2

                  if abs(diff_angle2)>=5:
                        simulation.input['angle_diff'] = diff_angle2

          # Evaluate system
                        simulation.compute()

          # Get output value
                        output_value = simulation.output['output']
                        T2-=output_value
                  else:
                        if abs(diff_angle3)>=10:
                              simulation.input['angle_diff'] = diff_angle2
                              simulation.compute()
                              output_value2 = simulation.output['output']
                              T3-=output_value2
                              
                        
                  time.sleep(0.05)


            except Exception as exc:
                  flag += 1
   
   
      set_angle4(0)
      time.sleep(2)
      T3=int(T3)
      if(T3>0):       
          for i in range (T3,0,-5):
                set_angle3(i)
                time.sleep(0.05)
      if(Object):
          for i in range(90,135,5):
                set_angle1(i)
                time.sleep(0.05)
                
      else:
          for i in range(90,45,-5):
                set_angle1(i)
                time.sleep(0.05)
      T2=int(T2)
      if(T2>110):     
          for i in range (T2,110,-5):
                set_angle2(i)
                time.sleep(0.05)
      set_angle4(180)
      time.sleep(1)
      set_angle2(180)
      time.sleep(1)
      set_angle3(40)
      time.sleep(1)
      set_angle1(90)
      time.sleep(1)
      client_socket.sendall(b'done\n')
      time.sleep(1)

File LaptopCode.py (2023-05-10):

import socket
import time
import skfuzzy as fuzz
from skfuzzy import control as ctrl
import numpy as np
import cv2




position=ctrl.Antecedent(np.arange(580, 900, 1), 'position')

position['H']=fuzz.smf(position.universe, 750, 900)
position['M']=fuzz.gaussmf(position.universe, 750, 40)
position['L']=fuzz.zmf(position.universe, 600, 750)

output=ctrl.Consequent(np.arange(0, 1, 0.01), 'output')

output['H']=fuzz.smf(output.universe, 0.6, 1)
output['M']=fuzz.gaussmf(output.universe, 0.6, 0.2)
output['L']=fuzz.zmf(output.universe, 0.4, 0.6)

rule1=ctrl.Rule(position['H'], output['H'])
rule2=ctrl.Rule(position['M'], output['M'])
rule3=ctrl.Rule(position['L'], output['L'])

fuzzy_ctrl=ctrl.ControlSystem([rule1, rule2, rule3])

simulation=ctrl.ControlSystemSimulation(fuzzy_ctrl)

# Set up network socket
client_socket = socket.socket(socket.AF_INET, socket.SOCK_STREAM)
client_socket.connect(('172.20.10.3', 5555)) #

net = cv2.dnn.readNet("dnn_model/yolov4-tiny.weights", "dnn_model/yolov4-tiny.cfg")
model = cv2.dnn_DetectionModel(net)
model.setInputParams(size = (320,320), scale = 1/255)
#load class names
classes =[]

with open("dnn_model/classes.txt", "r") as file_object:
    for class_name in file_object.readlines():
        class_name = class_name.strip()
        classes.append(class_name)
 
#initialize Camera

while True:

    cap = cv2.VideoCapture(1)

    cap.set(cv2.CAP_PROP_FRAME_WIDTH, 1280)
    cap.set(cv2.CAP_PROP_FRAME_HEIGHT, 720)
    cv2.namedWindow('frame')
    need_ctrl=True
    # cv2.setMouseCallback('frame', click_event)
    while need_ctrl :
        #get Frame
        ret, frame = cap.read()
        #object detection
        (class_ids, scores, bboxes)= model.detect(frame)
        for class_id, score, bbox in zip(class_ids, scores,bboxes):
            if classes[class_id] == "bottle" or classes[class_id] == 'cup':
                (x,y,w,h) = bbox
                class_name = classes[class_id]
                cv2.putText(frame,classes[class_id],(x,y-10), cv2.FONT_HERSHEY_COMPLEX, 2, (200, 0, 50), 2)
                cv2.rectangle(frame, (x,y),(x+w, y+h), (200, 0, 50), 3)
                
                #get position
                position = x 
                if position < 420:
                    need_ctrl = False
                    print(class_name)
                    #stop motor
                    client_socket.sendall(b'stop\n')
                    time.sleep(1)
                    if class_name == 'bottle':
                        client_socket.sendall(b'bottle\n')
                    else:
                        client_socket.sendall(b'cup\n')
                    time.sleep(1)
                    client_socket.sendall(b'stop_code\n')
                    
                else:
                    #fuzzy control
                    simulation.input['position']=position
                    simulation.compute()
                    output = simulation.output['output']
                    #send output to motor
                    client_socket.sendall(str(output).encode() + b'\n')
                    time.sleep(0.1)

    
            
    
        
        cv2.imshow("frame",frame)
        key=cv2.waitKey(1)
        if key == ord('q'):
            break 
    # release the camera and close the window
    cap.release()
    cv2.destroyAllWindows()
    
    while True:
        status = client_socket.recv(1024).decode().strip()
        if status == 'done':
            print('The Next Iteration is ready')
            break
    
# client_socket.sendall(b'done\n')


# Close network socket
client_socket.close()
